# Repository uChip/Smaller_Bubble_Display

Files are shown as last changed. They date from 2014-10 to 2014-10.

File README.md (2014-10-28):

# 8-digit 7-segment LED Display Module 

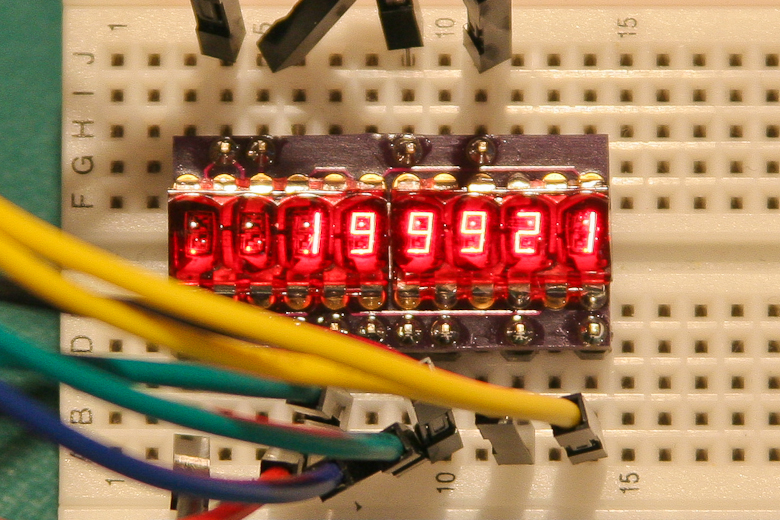
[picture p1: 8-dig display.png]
LED Display Module
  

This repo contains Eagle CAD PCB designs for an 8-digit LED display module based on the hp bubble display. The design files include schematic, board layout and BOM files.  There is also an Eagle library file that defines the module as an Eagle component.  

The module design utilizes a shift register to reduce the number of pins required to control the display.  

The software folder contains an Arduino sketch that provides example code to drive the display.   

See the file Forum-Posting.pdf for a more detailed explanation of the module design and software.  

## Order PCBs  

You can order this PCB directly from OSH Park.  Click on the following link.  
  * 8-digit Display Module - http://oshpark.com/shared_projects/oSSTCt4N 

See the Bill of Materials (BOM) file in the repo for a parts list.  

## Status  
  * Rev2 PCB has been tested to be functional.  

## File Formats  

Hardware design files are in "CadSoft EAGLE PCB Design Software" .brd and .sch formats.  A free version of the software can be downloaded from www.cadsoftusa.com. 

The example code is in Arduino .ino format (text).  A free version of the Arduino software can be downloaded from www.arduino.cc.  

## Distribution License  

You may use this PCB design however you like but no liability is accepted.

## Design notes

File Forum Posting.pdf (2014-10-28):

Hello!

I'm working on a new project that will use the hp Bubble display (https://www.sparkfun.com/products/12710) that is sold by SparkFun. I thought you might find this part of the project useful. The project is Arduino based and I have almost enough pins to drive two of the Bubble displays, maybe. Two displays would take 16 control lines. I don't have that many available, but I think I can devote 10 pins to the display. So I still have to reduce the pin count somehow. I could use the MAX7219CNG (https://www.sparkfun.com/products/9622) or the HT16K33 (http://www.adafruit.com/products/1427) driver parts but those each cost as much as adding a second Arduino. Or I could use the Arduino I2C design from my earlier posting, (https://forum.sparkfun.com/viewtopic.php?f=14&t=38056&p=170395&hilit=bubble#p170215) but that takes up a lot of PCB space.

Instead, what I did was build a smaller display module that has a shift register on the same PCB as the displays. The shift register, an SN74LV164APW, costs less than $0.50 and doesn't take up much space. You could also use a SN74LV595APWR which costs a few pennies more and takes up just a bit more space.

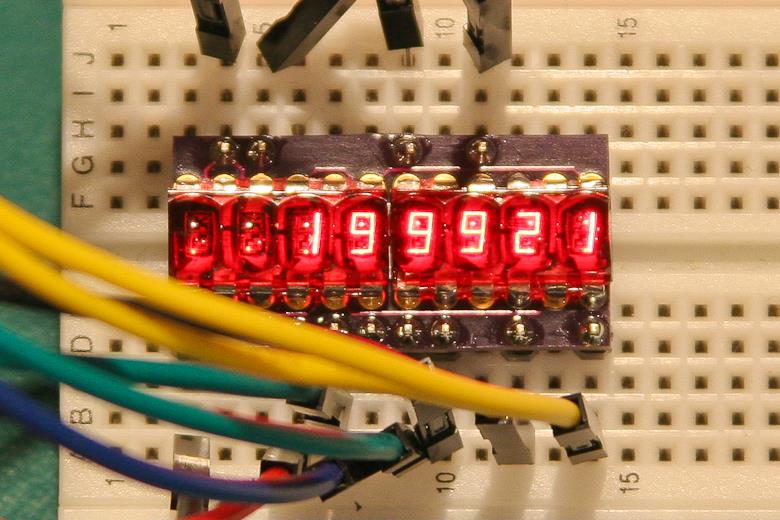
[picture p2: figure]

With the shift register, the eight (7 segments + decimal point) values are sent out serially using just 2 pins. This is not an I2C or SPI implementation. It's just a simple bit-bang serial drive directly to the shift register inputs. The other eight control lines, the digit selects, are driven directly from the Arduino.

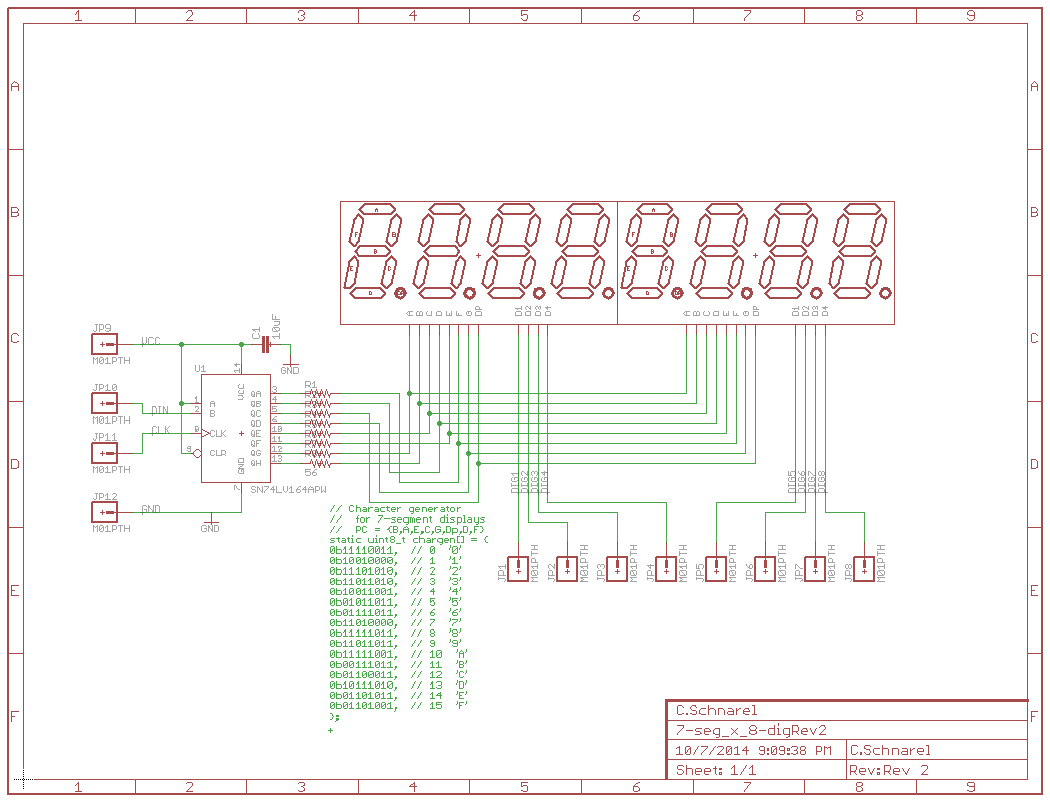
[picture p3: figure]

What? You don't see the shift register? Here is a picture of the back side of the PCB showing the shift register hidden on that side along with the current limit resistors. Note that I put the resistors on the segment lines, not the digit lines, so that brightness stays even no matter which character is being displayed.

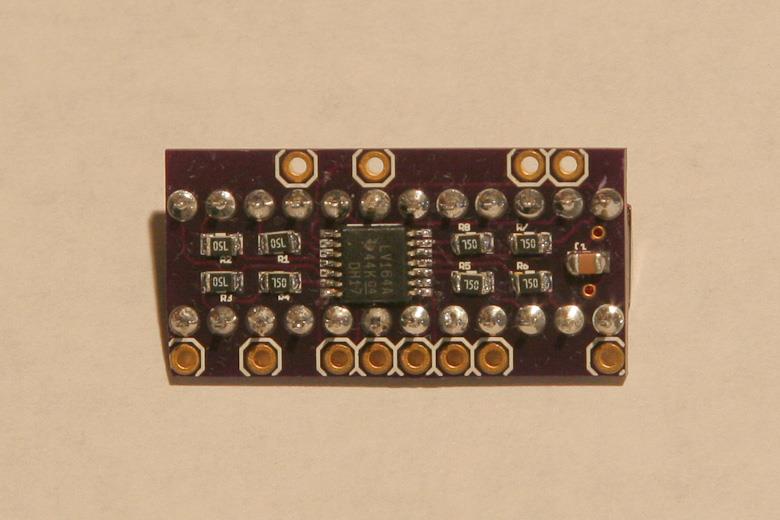
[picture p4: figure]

The shift register has nowhere near the drive capability needed to get maximum brightness from these displays. See my earlier posting for details on drive currents when multiplexing LEDs. (https://forum.sparkfun.com/viewtopic.php?f=14&t=38056&p=170395&hilit=bubble#p170215) In this case that is acceptable. It works well enough to be readable on my electronics bench and that's where this will be used.

To simplify and compact the PCB routing each shift register output is routed to whichever segment is most convenient. The simplified routing scrambles the segment order but we really don't care since the scramble is hidden in the character generator. In this case the bit order of the segments is (MSB to LSB) {B,A,E,C,G,Dp,D,F}.

This is about the third time I've had to rewrite the character generator to scramble the bit order to match a PCB. I got tired of doing it by hand so I wrote a program to do it for me. It's a simple program. I actually wrote it as an Arduino sketch. The #define statements at the top of the sketch specify what bit order you want. The program then prints out compiler ready code. Just copy/paste the code from the Arduino runtime window into your sketch.

I needed some example code to test out and demonstrate the display module. I decided a good example would be to implement a frequency counter. A Google search will turn up several Arduinobased frequency counter implementations. I tried a few of them and like Martin Nawrath’s (http://interface.khm.de/index.php/lab/experiments/arduino-frequency-counter-library/) the best. It is supposedly good to about 8 MHz and seemed pretty accurate and stable when I breadboarded it using my SparkFun RedBoard.

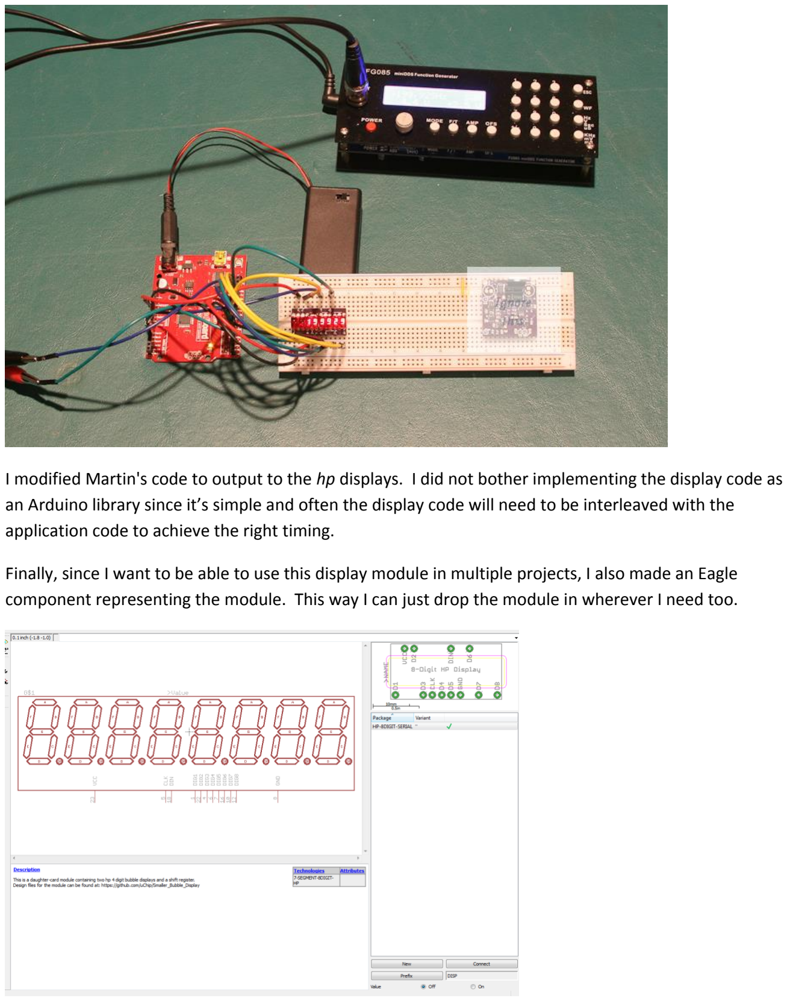
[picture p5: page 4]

I modified Martin's code to output to the hp displays. I did not bother implementing the display code as an Arduino library since it’s simple and often the display code will need to be interleaved with the application code to achieve the right timing.

Finally, since I want to be able to use this display module in multiple projects, I also made an Eagle component representing the module. This way I can just drop the module in wherever I need too.

All the most recent design files and code for this project can be found in the following GitHub repositories.

- Smaller_Bubble_Display (https://github.com/uChip/Smaller_Bubble_Display) - small 8-digit, 7-segment, LED display module
- Eagle files for display module & BOM
- Eagle Library with Display module as a component
- Display example code: Frequency counter based on Martin Nawrath’s library (http://interface.khm.de/index.php/lab/experiments/arduino-frequency-counter-library/)
- Bit_Swizzler (https://github.com/uChip/Bit_Swizzler) - Code to remap bits in character generator for 7-segment display

PCBs for the display module are available from OSHPark.com here. (https://oshpark.com/shared_projects/oSSTCt4N)

Good luck in all your projects!

- Chip

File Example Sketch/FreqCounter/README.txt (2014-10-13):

This example utilizes Martin Nawrath's FreqCounter library which can be found at:

  Martin Nawrath KHM LAB3
 Kunsthochschule f¸r Medien Kˆln
 Academy of Media Arts
 http://www.khm.de
 http://interface.khm.de/index.php/labor/experimente/

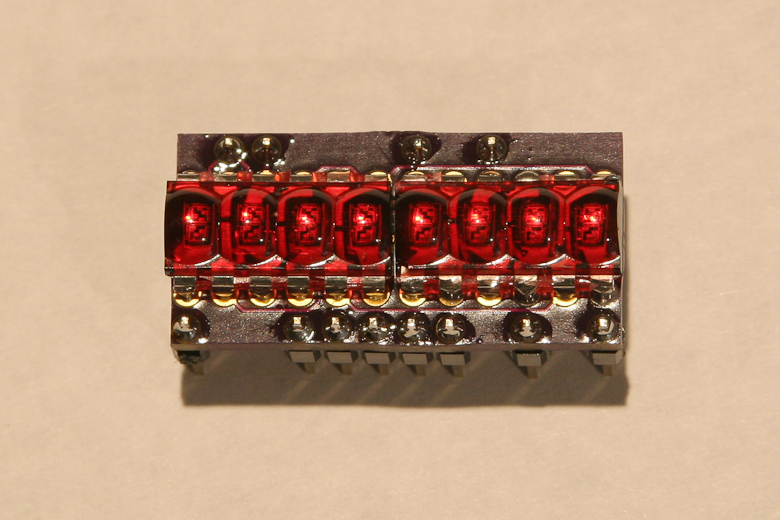
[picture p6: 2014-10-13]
module front.png

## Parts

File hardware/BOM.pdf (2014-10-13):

Qty Value | Device | Package | Parts | Description
8 56R | RESISTOR0805-RES 0805 | R1, R2, R3, R4, R5, R6, R7, R8 | Resistor
1 10uF | CAP0805 | 0805 | C1 | Capacitor
2 HP_DISPLAY | HP_DISPLAY | DIL12 | DISP1, DISP2 | SparkFun # COM-12710
1 SN74LV164APW SN74LV164APW | TSSOP-14(TI) U1 | 8-BIT SERIAL-IN PARALLEL-OUT SHIFT REGISTER with clear

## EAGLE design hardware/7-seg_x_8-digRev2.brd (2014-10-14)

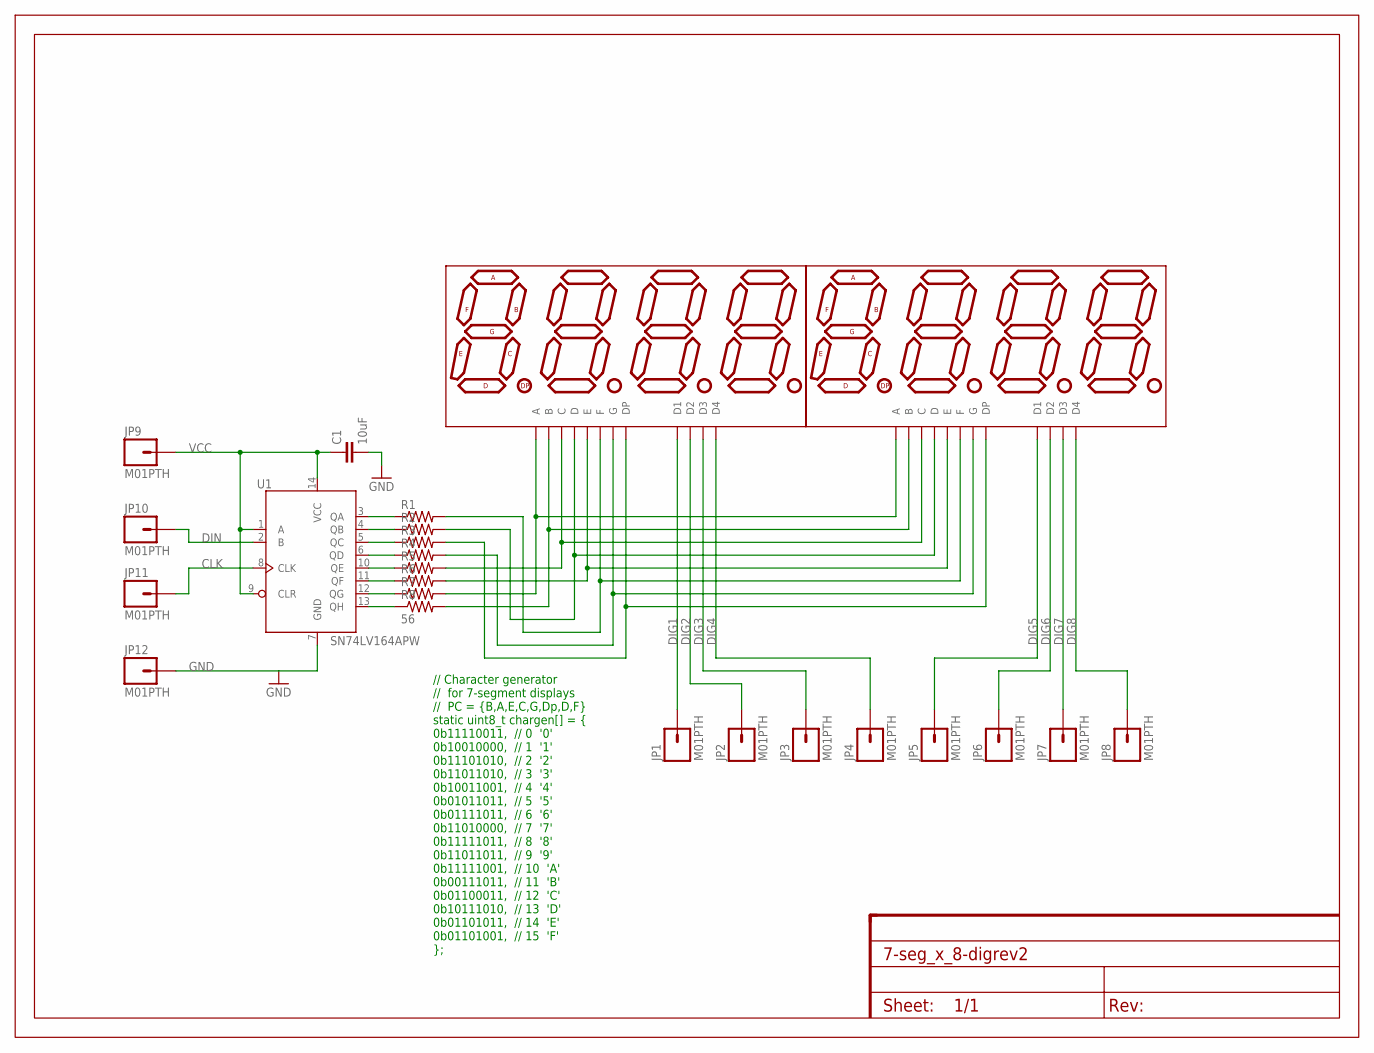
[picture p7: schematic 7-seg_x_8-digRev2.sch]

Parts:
C1: 10uF; 0805
FRAME1: FRAME_LTR_CU_MARK; FR-LTR-ON-PCB
JP1, JP2, JP3, JP4, JP5, JP6, JP7, JP8, JP9, JP10, JP11, JP12: M01PTH; 1X01
R1, R2, R3, R4, R5, R6, R7: RESISTOR0805-RES; 0805
R8: 56; 0805
U1: SN74LV164APW; TSSOP-14(TI)
U$1, U$2: HP_DISPLAY; DIL12

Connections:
CLK: JP11.1, U1.8 (CLK)
DIG1: JP1.1, U$1.1 (D1)
DIG2: JP2.1, U$1.10 (D2)
DIG3: JP3.1, U$1.4 (D3)
DIG4: JP4.1, U$1.6 (D4)
DIG5: JP5.1, U$2.1 (D1)
DIG6: JP6.1, U$2.10 (D2)
DIG7: JP7.1, U$2.4 (D3)
DIG8: JP8.1, U$2.6 (D4)
DIN: JP10.1, U1.2 (B)
GND: C1.2, JP12.1, U1.7 (GND)
unnamed: R1.1, U1.3 (QA)
unnamed: R2.1, U1.4 (QB)
unnamed: R3.1, U1.5 (QC)
unnamed: R4.1, U1.6 (QD)
unnamed: R5.1, U1.10 (QE)
unnamed: R6.1, U1.11 (QF)
unnamed: R7.1, U1.12 (QG)
unnamed: R8.1, U1.13 (QH)
SEGA: R7.2, U$1.12 (A), U$2.12 (A)
SEGB: R8.2, U$1.11 (B), U$2.11 (B)
SEGC: R5.2, U$1.3 (C), U$2.3 (C)
SEGD: R2.2, U$1.8 (D), U$2.8 (D)
SEGDP: R3.2, U$1.5 (DP), U$2.5 (DP)
SEGE: R6.2, U$1.2 (E), U$2.2 (E)
SEGF: R1.2, U$1.9 (F), U$2.9 (F)
SEGG: R4.2, U$1.7 (G), U$2.7 (G)
VCC: C1.1, JP9.1, U1.1 (A), U1.9 (CLR), U1.14 (VCC)

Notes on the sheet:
// Character generator // for 7-segment displays // PC = {B,A,E,C,G,Dp,D,F} static uint8_t chargen[] = { 0b11110011, // 0 '0' 0b10010000, // 1 '1' 0b11101010, // 2 '2' 0b11011010, // 3 '3' 0b10011001, // 4 '4' 0b01011011, // 5 '5' 0b01111011, // 6 '6' 0b11010000, // 7 '7' 0b11111011, // 8 '8' 0b110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

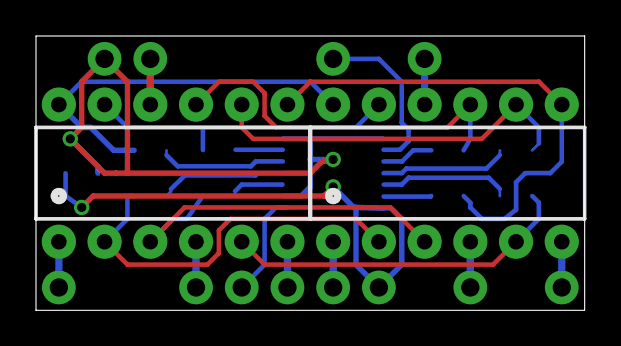
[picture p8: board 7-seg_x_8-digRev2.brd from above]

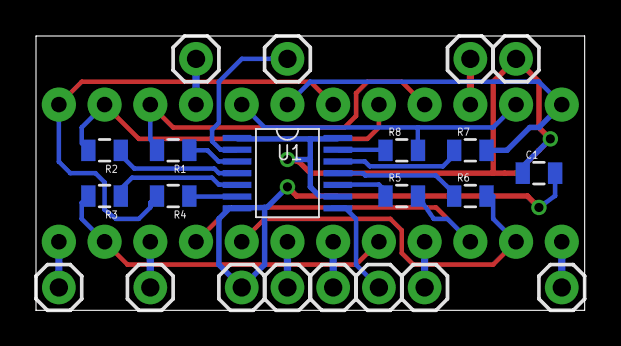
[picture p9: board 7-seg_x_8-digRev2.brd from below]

Board: 2 copper layers, 30.5 x 15.2 mm, 25 parts (23 on the bottom side), 28 nets.

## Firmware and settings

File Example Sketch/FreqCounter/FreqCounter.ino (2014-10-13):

/*
 FreqCounter library from:
 
  Martin Nawrath KHM LAB3
 Kunsthochschule f¸r Medien Kˆln
 Academy of Media Arts
 http://www.khm.de
 http://interface.khm.de/index.php/labor/experimente/	
 */
#include <FreqCounter.h>

// Frequency counter input pin
// Defined in FreqCounter.h
//#define FC 5

// Pins to drive Segment Shift Register
#define SR_DATA A0
#define SR_CLK A1

// Display digit pins
#define DIGIT_1 4
#define DIGIT_2 6
#define DIGIT_3 7
#define DIGIT_4 8
#define DIGIT_5 9
#define DIGIT_6 10
#define DIGIT_7 11
#define DIGIT_8 12

// Gate LED
#define GATE_LED 13

// This sets the delay time for frame rate
// The value is repeated for each of the digits on the display so 
//   frame rate = 1 / (8 * DIGIT_TIME(uS)) -> 125 Hz
#define DIGIT_TIME 1000

// Character generator for 7-segment displays
//  PC = {B,A,E,C,G,Dp,D,F}
static uint8_t chargen[] = {
  0b11110011,  // 0  '0'
  0b10010000,  // 1  '1'
  0b11101010,  // 2  '2'
  0b11011010,  // 3  '3'
  0b10011001,  // 4  '4'
  0b01011011,  // 5  '5'
  0b01111011,  // 6  '6'
  0b11010000,  // 7  '7'
  0b11111011,  // 8  '8'
  0b11011011,  // 9  '9'
  0b11111001,  // 10  'A'
  0b00111011,  // 11  'B'
  0b01100011,  // 12  'C'
  0b10111010,  // 13  'D'
  0b01101011,  // 14  'E'
  0b01101001,  // 15  'F'
  0b00000000,  // 16  " "
};

unsigned long frq;
unsigned long num = 0;
int cnt;
int DispBCD = 0;
boolean leadzero = true;

void setup() {
  pinMode(GATE_LED, OUTPUT);

  Serial.begin(115200);        // connect to the serial port

  Serial.println("Frequency Counter");

  pinMode(SR_DATA, OUTPUT);
  pinMode(SR_CLK, OUTPUT);

  // set up the digit control pins
  pinMode(DIGIT_1, OUTPUT);
  pinMode(DIGIT_2, OUTPUT);
  pinMode(DIGIT_3, OUTPUT);
  pinMode(DIGIT_4, OUTPUT);
  pinMode(DIGIT_5, OUTPUT);
  pinMode(DIGIT_6, OUTPUT);
  pinMode(DIGIT_7, OUTPUT);
  pinMode(DIGIT_8, OUTPUT);

  // Set up to take a frequency sample (to kick things off)
  FreqCounter::f_comp=162;   // Cal Value / Calibrate with professional Freq Counter
  FreqCounter::start(1000);  // 100 ms Gate Time
}



void loop() {

  if(FreqCounter::f_ready != 0) {  // if a new value is available
    frq=FreqCounter::f_freq;       // get the value
    Serial.print(cnt++);
    Serial.print("  Freq: ");
    Serial.println(frq);
    
    // then set up to take the next measurement
    FreqCounter::f_comp=162;   // Cal Value / Calibrate with professional Freq Counter
    FreqCounter::start(1000);  // 100 ms Gate Time
  }

  // Convert the binary value into decimal digits
  // then multiplex the display using the digits
  num = frq;
  leadzero = true;
  
  DispBCD = 0;
  if(leadzero && num<10000000)DispBCD = 16;
  while(num >= 10000000) { DispBCD++; num-=10000000; leadzero=false; }
  ShiftOut(chargen[DispBCD]);
  digitalWrite(DIGIT_1, LOW);
  delayMicroseconds(DIGIT_TIME);
  digitalWrite(DIGIT_1, HIGH);

  DispBCD = 0;
  if(leadzero && num<1000000)DispBCD = 16;
  while(num >= 1000000) { DispBCD++; num-=1000000; leadzero=false; }
  ShiftOut(chargen[DispBCD]);
  digitalWrite(DIGIT_2, LOW);
  delayMicroseconds(DIGIT_TIME);
  digitalWrite(DIGIT_2, HIGH);

  DispBCD = 0;
  if(leadzero && num<100000)DispBCD = 16;
  while(num >= 100000)  { DispBCD++; num-=100000; leadzero=false; }
  ShiftOut(chargen[DispBCD]);
  digitalWrite(DIGIT_3, LOW);
  delayMicroseconds(DIGIT_TIME);
  digitalWrite(DIGIT_3, HIGH);

  DispBCD = 0;
  if(leadzero && num<10000)DispBCD = 16;
  while(num >= 10000) { DispBCD++; num-=10000; leadzero=false; }
  ShiftOut(chargen[DispBCD]);
  digitalWrite(DIGIT_4, LOW);
  delayMicroseconds(DIGIT_TIME);
  digitalWrite(DIGIT_4, HIGH);

  DispBCD = 0;
  if(leadzero && num<1000)DispBCD = 16;
  while(num >= 1000)  { DispBCD++; num-=1000; leadzero=false; }
  ShiftOut(chargen[DispBCD]);
  digitalWrite(DIGIT_5, LOW);
  delayMicroseconds(DIGIT_TIME);
  digitalWrite(DIGIT_5, HIGH);

  DispBCD = 0;
  if(leadzero && num<100)DispBCD = 16;
  while(num >= 100) { DispBCD++; num-=100; leadzero=false; }
  ShiftOut(chargen[DispBCD]);
  digitalWrite(DIGIT_6, LOW);
  delayMicroseconds(DIGIT_TIME);
  digitalWrite(DIGIT_6, HIGH);

  DispBCD = 0;
  if(leadzero && num<10)DispBCD = 16;
  while(num >= 10)  { DispBCD++; num-=10; leadzero=false; }
  ShiftOut(chargen[DispBCD]);
  digitalWrite(DIGIT_7, LOW);
  delayMicroseconds(DIGIT_TIME);
  digitalWrite(DIGIT_7, HIGH);

  ShiftOut(chargen[num]);
  digitalWrite(DIGIT_8, LOW);
  delayMicroseconds(DIGIT_TIME);
  digitalWrite(DIGIT_8, HIGH);
}  

//-=|=-=|=-=|=-=|=-=|=-=|=-=|=-=|=-=|=-=|=-=|=-=|=-=|=-=|=-=|=-=|
void ShiftOut(uint8_t data) {
  digitalWrite(SR_DATA, (data & 0x80));
  digitalWrite(SR_CLK, LOW);
  digitalWrite(SR_CLK, HIGH);
  digitalWrite(SR_DATA, (data & 0x40));
  digitalWrite(SR_CLK, LOW);
  digitalWrite(SR_CLK, HIGH);
  digitalWrite(SR_DATA, (data & 0x20));
  digitalWrite(SR_CLK, LOW);
  digitalWrite(SR_CLK, HIGH);
  digitalWrite(SR_DATA, (data & 0x10));
  digitalWrite(SR_CLK, LOW);
  digitalWrite(SR_CLK, HIGH);
  digitalWrite(SR_DATA, (data & 0x08));
  digitalWrite(SR_CLK, LOW);
  digitalWrite(SR_CLK, HIGH);
  digitalWrite(SR_DATA, (data & 0x04));
  digitalWrite(SR_CLK, LOW);
  digitalWrite(SR_CLK, HIGH);
  digitalWrite(SR_DATA, (data & 0x02));
  digitalWrite(SR_CLK, LOW);
  digitalWrite(SR_CLK, HIGH);
  digitalWrite(SR_DATA, (data & 0x01));
  digitalWrite(SR_CLK, LOW);
  digitalWrite(SR_CLK, HIGH);
}

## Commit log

2014-10-13 Added Eagle and Arduino files
    [7-seg_x_8-digRev2.brd, 7-seg_x_8-digRev2.sch]
2014-10-13 First cut at README. Still mostly placeholder
2014-10-14 Updating to latest versions of PCB files
    [7-seg_x_8-digRev2.brd, 7-seg_x_8-digRev2.sch]
2014-10-28 Updated to latest board Rev & added forum posting doc

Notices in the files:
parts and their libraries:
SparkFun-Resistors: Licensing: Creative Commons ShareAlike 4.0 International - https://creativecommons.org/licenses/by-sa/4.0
